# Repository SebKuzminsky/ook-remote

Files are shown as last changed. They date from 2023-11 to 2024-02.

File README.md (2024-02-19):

# Introduction

This is a minimal effort transmitter for 433 MHz On-Off Keyed/Amplitude
Shift Keyed remote control signals.

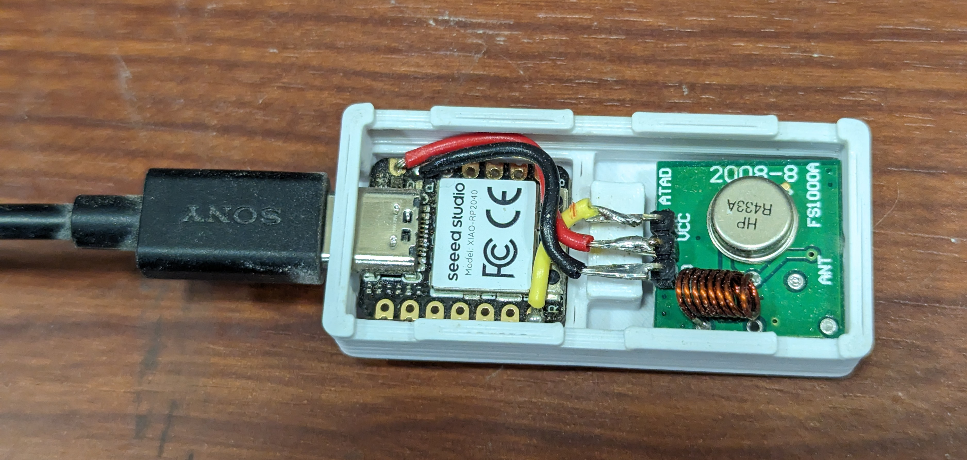
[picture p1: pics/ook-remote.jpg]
ook-remote with case open


It's built using a Seeed Studios XIAO RP2040 and a FS1000A (433 MHz
ASK transmitter).

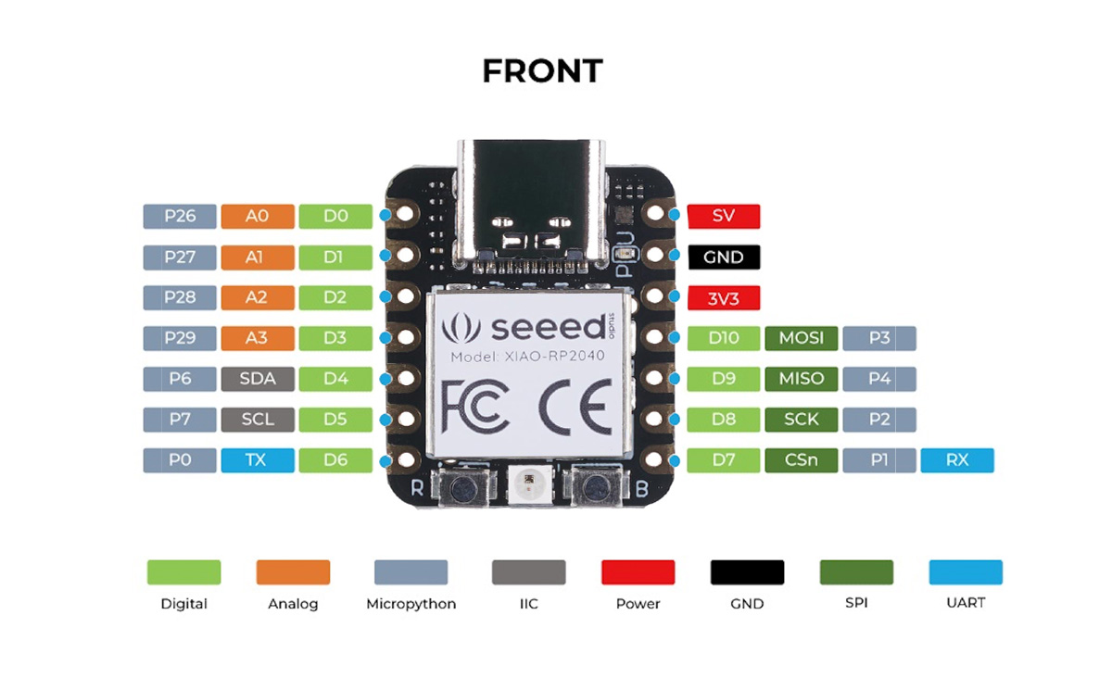
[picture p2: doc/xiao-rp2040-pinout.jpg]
xiao rp2040 pinout
* <https://wiki.seeedstudio.com/XIAO-RP2040/> 

* <https://components101.com/modules/433-mhz-rf-transmitter-module>
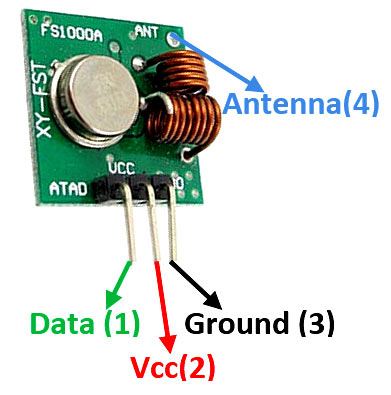
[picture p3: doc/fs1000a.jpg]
fs1000a pinout


Some versions of the FS1000A use two coil inductors (as pictured above),
and some use just one coil and one surface mount inductor on the back
of the board.  I think both versions should work just fine.

# Wiring

If you intend to use the enclosure, make sure to route the wires so
they don't interfere with the "clamp" that holds the Xiao RP2040 board
in place.

Super simple wiring:

```
Xiao RP2040      | FS1000A
-----------------+--------
Vbus/5V          | Vcc
GND              | GND
GPIO0 (P0/TX/D6) | ATAD
```

The antenna is optional, for me it worked fine without.  If you want one,
solder a 1/4 wave antenna (173 mm of wire) to the FS1000A antenna via.
NOTE: Carefully select the correct hole for this, as the silkscreen on
these cheap boards is all over the place.

# Reverse engineering the original remote's signal

The immediate goal is to clone the remote for a WEN 3410 air filter
(<https://wenproducts.com/products/Air-Filtration-System-Item-3410>).

I used a HackRF One (<https://greatscottgadgets.com/hackrf/one/>) and
GQRX to find the frequency of the original remote.

I then used `hackrf_transfer` to record the signals sent by the "on"
and "off" buttons:

Capture:

```
$ hackrf_transfer -s 2000000 -f 433920000 -r on.complex16
$ hackrf_transfer -s 2000000 -f 433920000 -r off.complex16
```

Replay:

```
$ hackrf_transfer -s 2000000 -f 433920000 -a1 -x24 -t on.complex16
$ hackrf_transfer -s 2000000 -f 433920000 -a1 -x24 -t on.complex16
$ hackrf_transfer -s 2000000 -f 433920000 -a1 -x24 -t on.complex16
$ hackrf_transfer -s 2000000 -f 433920000 -a1 -x24 -t off.complex16
```

## Demodulating with Universal Radio Hacker

I used Universal Radio Hacker (URH, <https://github.com/jopohl/urh>) to
analyze the recorded signals.  URH needs the filename extensions to be
`.complex16s`.

This is what the remote sends when I click the "On" button.  We can see
one "header" burst, followed by three similar-looking burst:

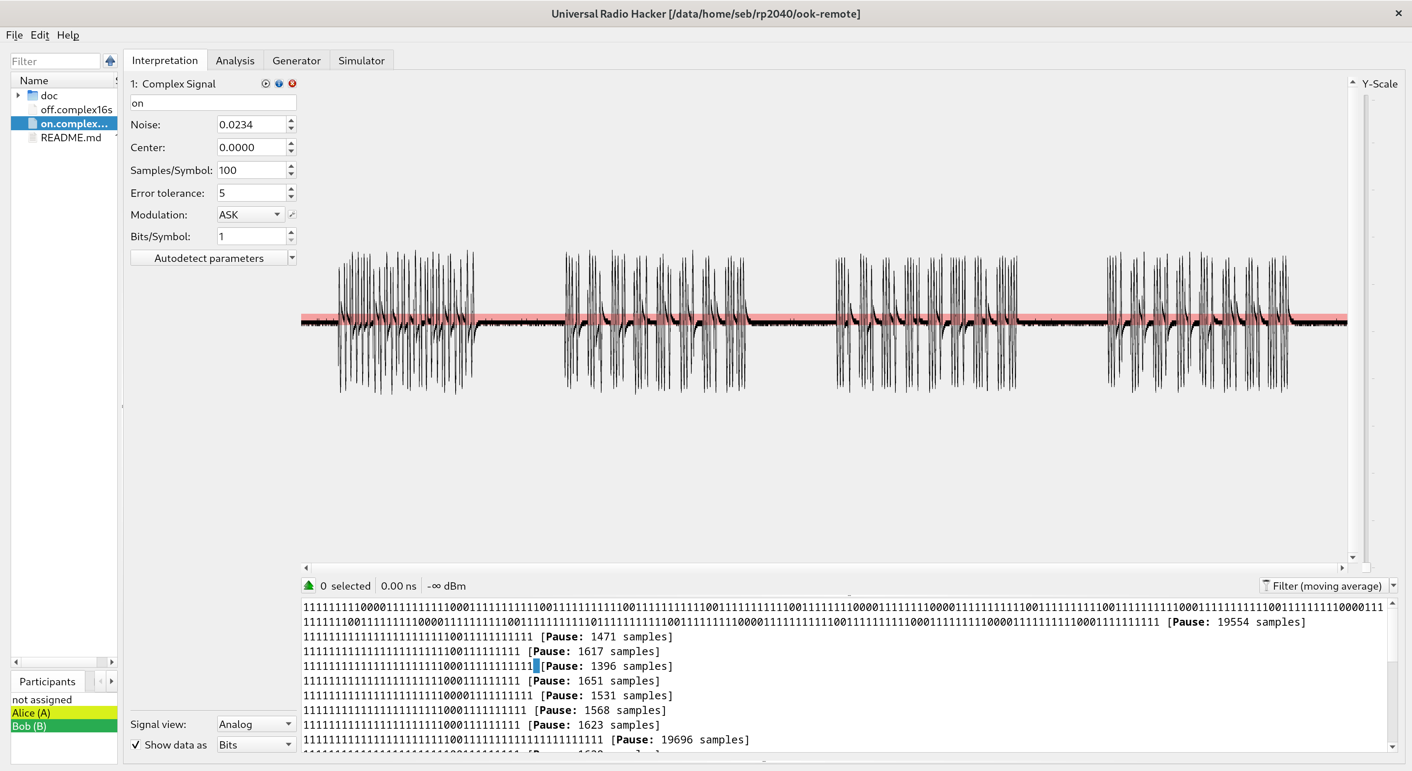
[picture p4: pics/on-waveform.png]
"on" waveform picture


Zooming in on the second burst we can see the On-Off Keying, where the
constant-frequency carrier wave is sometimes transmitted and sometimes
not:

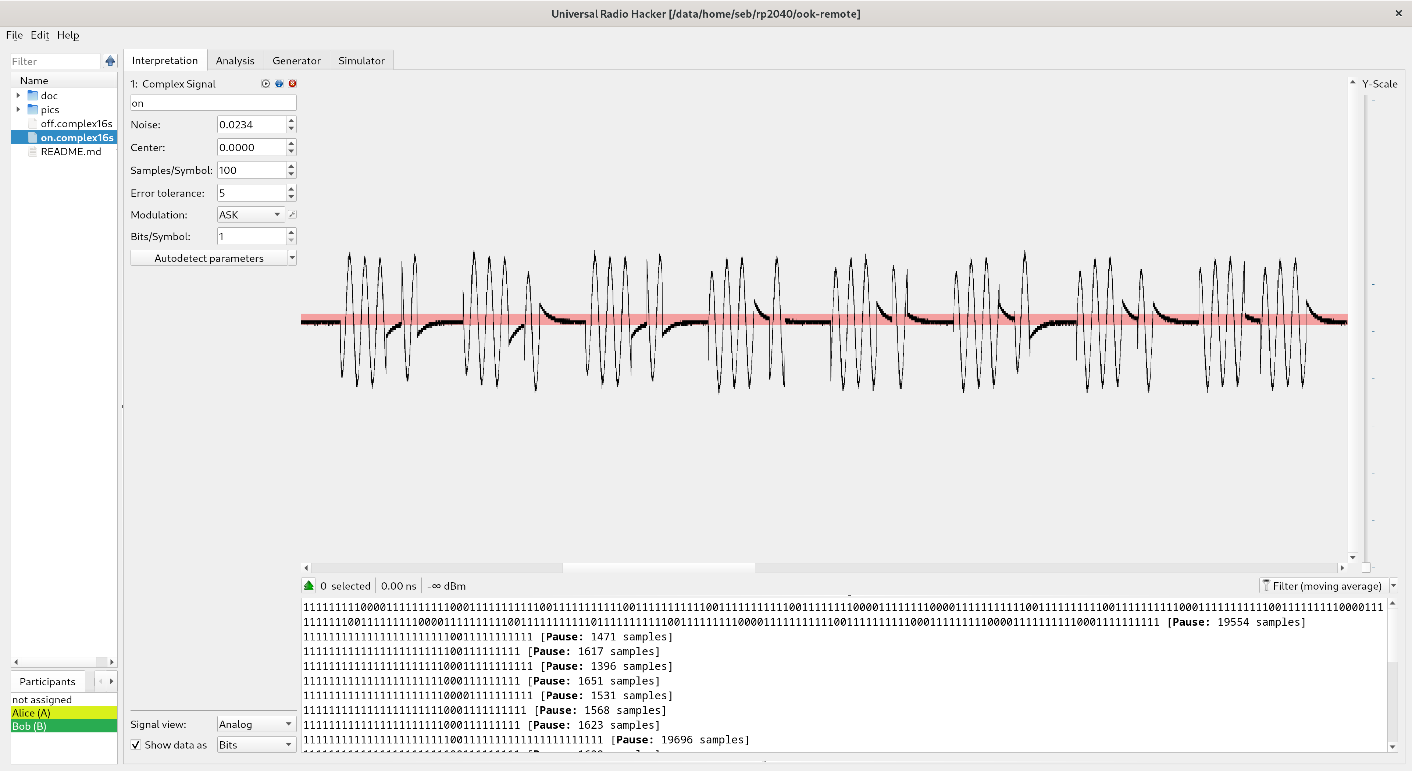
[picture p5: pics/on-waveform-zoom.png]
"on" waveform zoomed picture


Zooming in more and selecting what looks like a single symbol/bit we
get an approximate symbol size of 621 samples, or 310 microseconds:

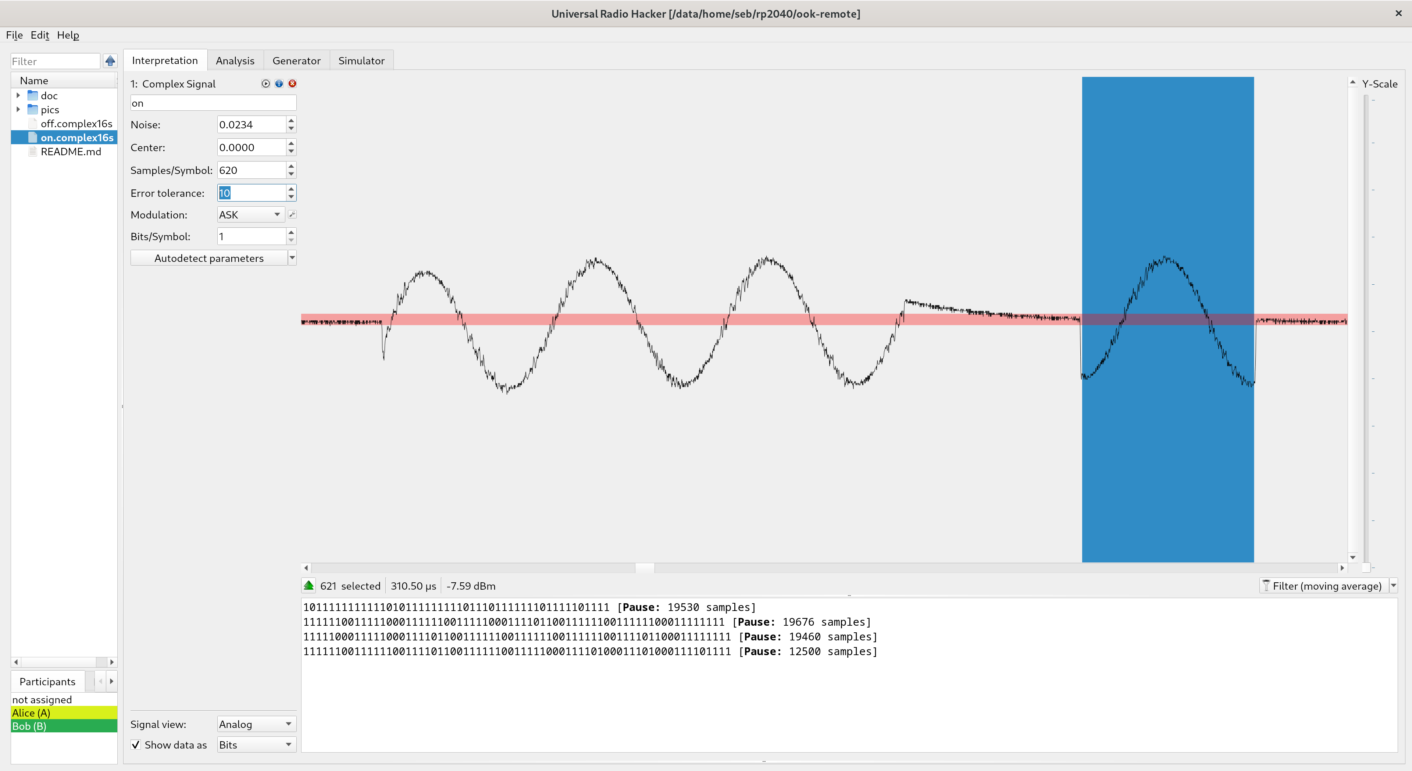
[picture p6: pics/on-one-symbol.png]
one bit picture


I then switched to the demodulated signal view and adjusted the noise
and center to clean up the decoding.  This is starting to look good:

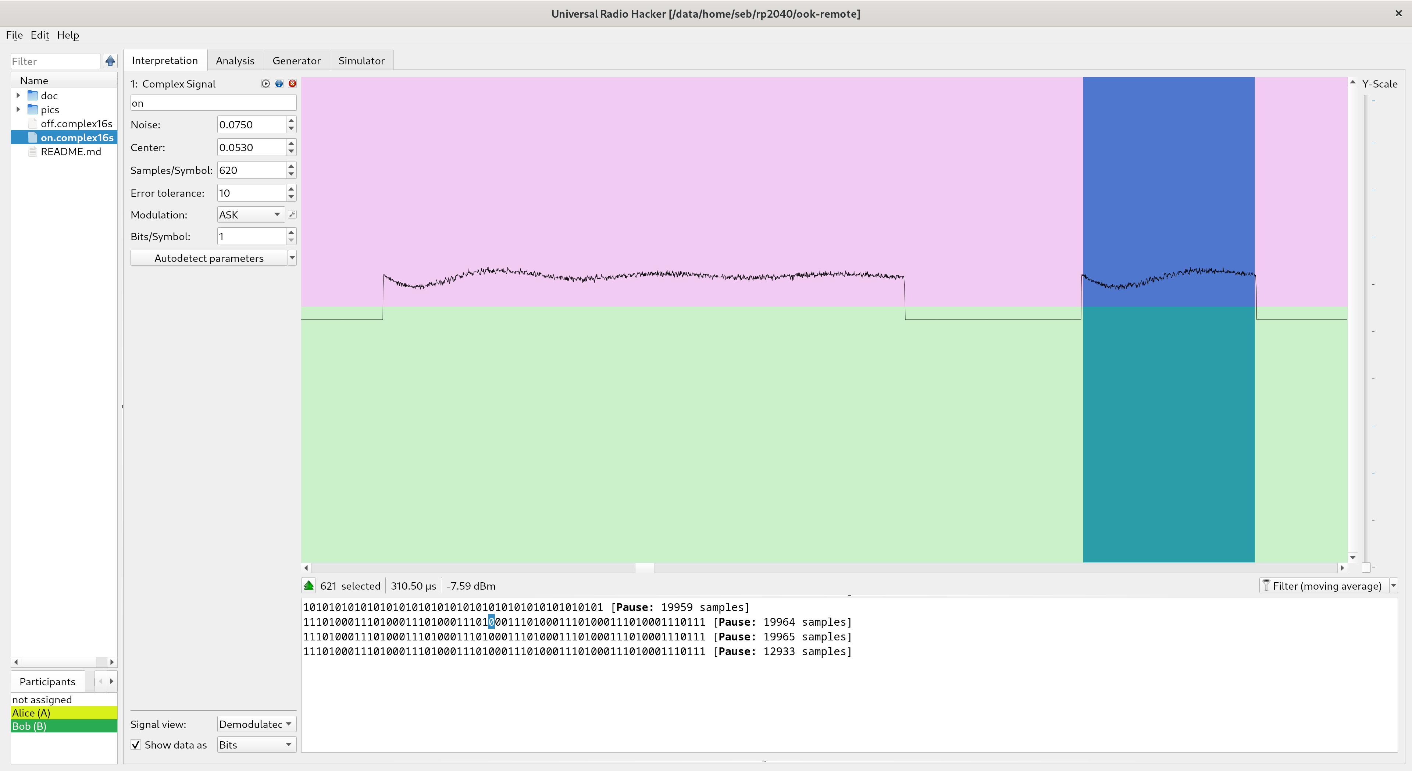
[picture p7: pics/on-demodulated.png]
demodulated picture


Loading the "off" signal, demodulating it in the same way, and comparing
them.  We see that there's a small difference in the middle of the
data burst:

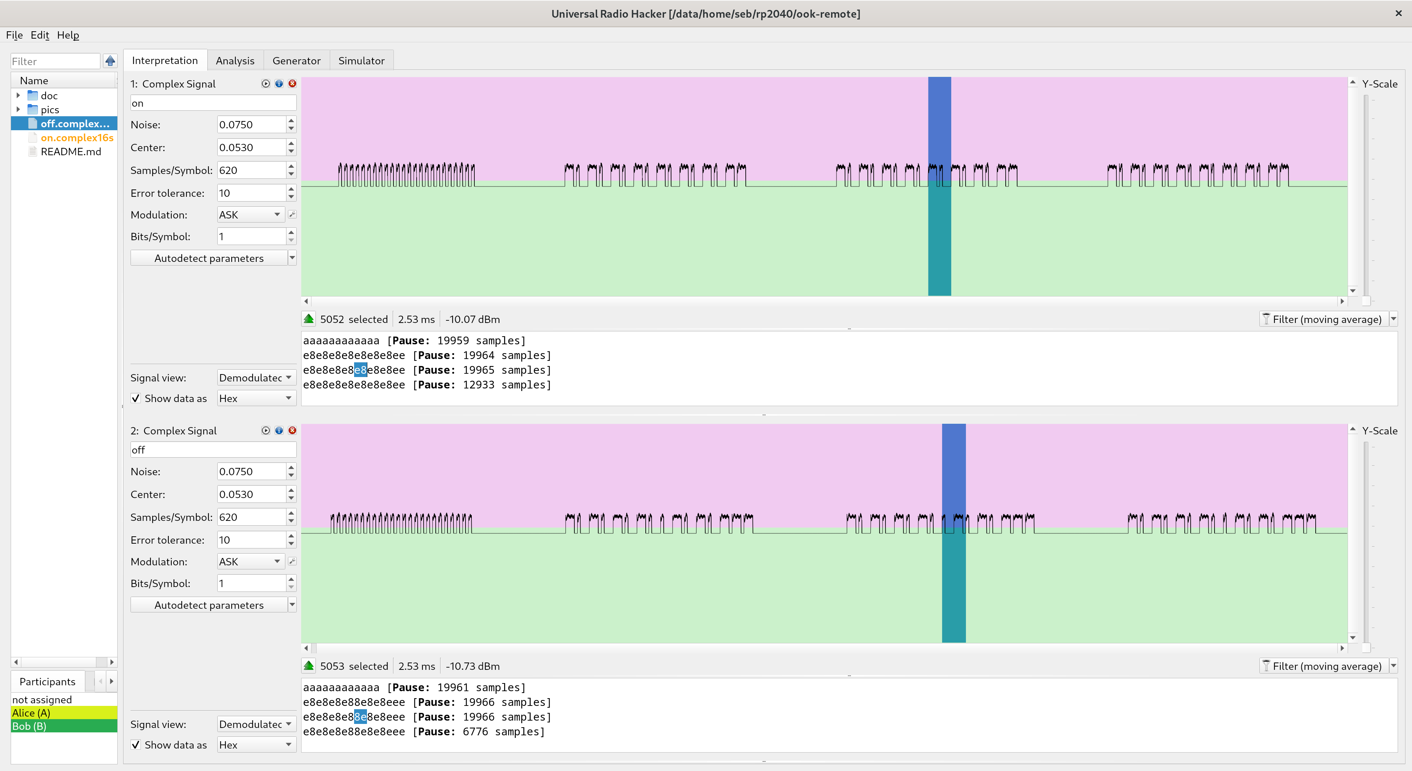
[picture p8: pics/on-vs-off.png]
on-vs-off picture


# FS1000A radio info

## Modulation theory

On-Off Keying: <https://en.wikipedia.org/wiki/On%E2%80%93off_keying>

Amplitude Shift Keying: <https://en.wikipedia.org/wiki/Amplitude-shift_keying>

## Radio tranceiver

* Martyn Davies' excellent explanation of ASK,
  OOK, and the FS1000A/XY-MK-5V transceiver:
  <https://www.youtube.com/watch?v=w6V9NyXwohI>

* <https://theorycircuit.com/fs1000a-433mhz-rf-transmitter-and-receiver-brief-note/>

# Other similar projects & info

* <http://www.ignorantofthings.com/2018/11/reverse-engineering-433mhz-remote.html>

* <https://forums.raspberrypi.com/viewtopic.php?t=58420>

* <http://www.hoagieshouse.com/RaspberryPi/RCSockets/RCPlug.html>

## Alternative radio

The FS1000A is the simplest radio transmitter imaginable, and inexpensive.

It's tempting to build a much more capable radio toy, perhaps using
the [CC1101](https://www.ti.com/product/CC1101) (available on ebay,
$10 board including SMA connector and antenna).

CC1101 based project: <https://github.com/mcore1976/cc1101-tool>

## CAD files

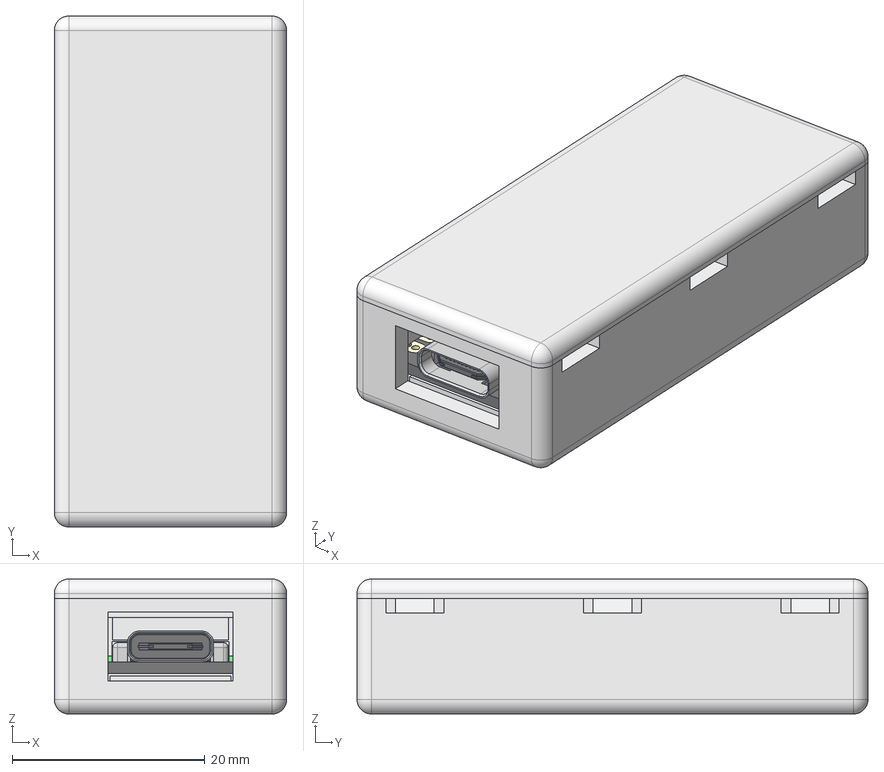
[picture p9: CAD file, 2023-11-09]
enclosure/enclosure.FCStd
24.1 x 53.0 x 14.0 mm
FS1000A
bottom
lid
type-c v2
type-c v003
type-c v004
type-c v005
type-c v006
type-c v007
type-c v008
type-c v009
type-c v010
type-c v011
type-c v012
type-c v013
type-c v014
type-c v015
type-c v016
type-c v017
type-c v018
type-c v019
type-c v020
type-c v021
type-c v022
type-c v023
type-c v024
type-c v025
smd_button v3
DOUT
DIN
VSS
VDD
smd_button v3(Mirror)

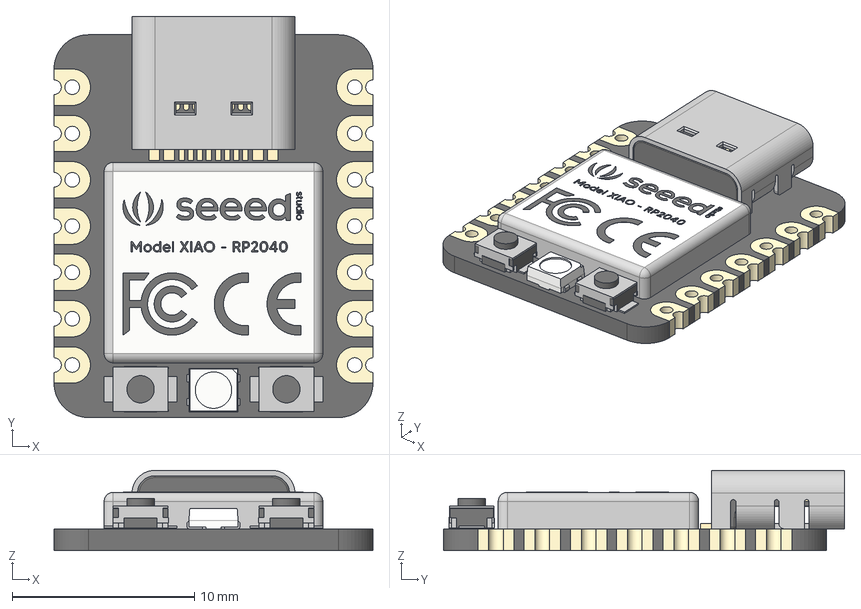
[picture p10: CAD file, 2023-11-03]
enclosure/Seeed Studio XIAO RP2040 v26.step
17.5 x 22.0 x 4.40 mm
type-c v2
smd_button v3
DOUT
DIN
VSS
VDD
smd_button v3(Mirror)

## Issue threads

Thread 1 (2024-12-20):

Is the Wen 3417 Remote the same?

puterboy, 2024-12-20:
The Wen 3417 Air Filtration device seems to be a more powerful version of the Wen 3410 Air Filtration system.

Externally the remotes look identical.

I am asking because I would like to be able to control my Wen Air Filtration system via Home Assistant using Open MQTT Gateway esp32-based RTL433 decoder -- I already use it to read many other 433MHZ-based devices.

Any idea if it is compatible with RTL433 decoder project?

SebKuzminsky, 2024-12-22:
No idea, sorry.

Closed 2024-12-22.

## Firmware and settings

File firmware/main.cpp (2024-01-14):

#include <cstdio>
#include <ctype.h>
#include <string.h>
#include <stdlib.h>

#include "pico/stdlib.h"
#include "hardware/clocks.h"

#include "ook.pio.h"


// Rising edge on this GPIO indicates beginning of a transmission,
// used to trigger a scope for debugging.
uint const debug_gpio = 1;


bool debug_flag = false;

#define debug(fmt, ...) \
    do { if (debug_flag) printf(fmt, ## __VA_ARGS__); } while (0)


// Process commands received from the computer via USB serial.
// Valid input strings:
//     'txN': N is a 32-bit hex string.  Transmit the hex string.
void process_input(char const * in) {
    if (strncasecmp("tx", in, 2) == 0) {
        uint32_t data = 0;
        int r;
        r = sscanf(&in[2], "%lx", &data);
        if (r != 1) {
            printf("failed to parse '%s'\n", in);
            return;
        }
        debug("tx 0x%08lx\n", data);
        gpio_put(debug_gpio, 1);
        ook_send(data);
        gpio_put(debug_gpio, 0);

    } else if (strncasecmp("us-per-bit", in, 10) == 0) {
        uint us_per_bit = 0;
        int r;
        r = sscanf(&in[10], "%u", &us_per_bit);
        if (r != 1) {
            printf("failed to parse '%s'\n", in);
            return;
        }
        debug("us-per-bit %u\n", us_per_bit);
        ook_start(us_per_bit);

    } else if (strncasecmp("debug", in, 5) == 0) {
        debug_flag = !debug_flag;
        debug("debug is %d\n", debug_flag);

    } else {
        printf("unknown input '%s'\n", in);
    }
}


void read_serial(void) {
    static char in[16];
    static int index = 0;

    // Block waiting for an input character.
    in[index] = getchar();
    if (isspace(in[index])) {
        in[index] = '\0';
        process_input(in);
        index = 0;
        return;
    }
    ++index;
    if (index == sizeof(in)) {
        printf("input buffer overflow, discarding input '%s'\n", in);
        index = 0;
    }
}


int main() {
    PIO ook_pio = pio0;
    uint const ook_gpio = 0;

    stdio_init_all();
    clocks_init();

    gpio_init(debug_gpio);
    gpio_set_function(debug_gpio, GPIO_FUNC_SIO);
    gpio_set_dir(debug_gpio, true);  // output
    gpio_put(debug_gpio, 0);

    gpio_init(ook_gpio);
    gpio_set_function(ook_gpio, GPIO_FUNC_PIO0);
    gpio_set_dir(ook_gpio, true);  // output

    pio_add_program_at_offset(ook_pio, &ook_program, 0);
    ook_init(ook_pio, ook_gpio);
    ook_start(312);

    for (;;) {
        read_serial();
    }
}

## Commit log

2023-11-02 start adding an enclosure
    [enclosure.FCStd]
2023-11-03 lots of improvements to the enclosure
    [Seeed Studio XIAO RP2040 v26.step, enclosure-bottom.stl, enclosure-lid.stl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]
2023-11-03 enclosure: make the xiao fence lower
    This makes it not interact so weirdly with the latching groove.
    [enclosure-bottom.stl, enclosure.FCStd]
2023-11-03 enclosure: better snap-fit latches
    [enclosure-lid.stl, enclosure.FCStd]
2023-11-03 enclosure: raise the xiao up a little bit, to make more room for soldered wires
    [enclosure-bottom.stl, enclosure-lid.stl, enclosure.FCStd]
2023-11-04 enclosure: more & sturdier latches
    [enclosure-bottom.stl, enclosure-lid.stl, enclosure.FCStd]
2023-11-04 add recordings of all the remote buttons
2023-11-04 enclosure: fillet the bottom face too
    [enclosure-bottom.stl, enclosure.FCStd]
2023-11-04 enclosure: center the antenna hole for aesthetics
    [enclosure-bottom.stl, enclosure.FCStd]
2023-11-04 enclosure: center the usb-c connector vertically, for aesthetics
    [enclosure-bottom.stl, enclosure-lid.stl, enclosure.FCStd]
2023-11-08 build for Seeed Xiao RP2040, not Raspberry Pi Pico
    The Xiao is much smaller in physical dimensions, not much more costly
    than the Pico, and has plenty of IO for this application. Plus it has
    USB-C and a reset button, and an RGB led.
2023-11-09 oops, fix the wen3410 bit rate
    [main.cpp]
2023-11-09 enclosure: shrink to fit the actual fs1000a board
    [enclosure-bottom.stl, enclosure-lid.stl, enclosure.FCStd]
2023-11-09 firmware: handle parse errors better
    [main.cpp]
2023-11-09 ook-remote cli: remove a bunch of debug prints
2023-11-10 cli: use argparse to get the serial device name
2023-11-11 README: note that the antenna is optional
2024-01-14 fix a harmless copy/paste error in firmware
    [main.cpp]
